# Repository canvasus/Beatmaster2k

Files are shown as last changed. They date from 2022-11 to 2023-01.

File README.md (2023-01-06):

# Beatmaster2k

A rudimentary step sequencer based on a Teensy 4.1 and a Novation Launchpad. 
It is mainly intended as a "jamming partner", not a full-fledged production tool.

Some basic features/specs:

- 7 Tracks. Can be set to output midi on serial, device or host ports
- 8 Patterns per track currently, but lots of room for expansion
- 64 Scenes, i.e combination of patterns

- Patterns are edited on the Launchpad. Works during playing
- Patterns can be set to any length between 1 and 128 steps
- Patterns have configurable speed

- Patterns and other settings stored on SD card

Component list:
- Teensy 4.1
- SD card
- ILI9341 display (touch is not used atm)
- 2 encoders
- 8 buttons via an MPC23017 expander
- Powered usb hub
- Novation Launchpad Mini Mk3

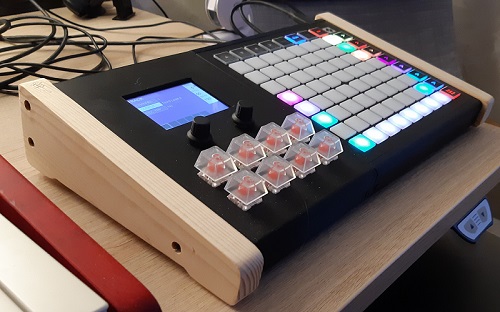
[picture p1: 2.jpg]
prototype1


(prototype assembly)

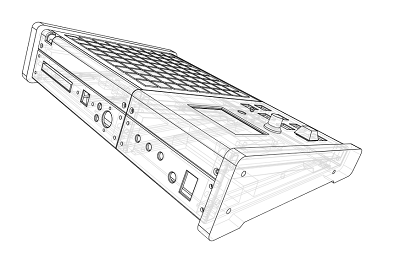
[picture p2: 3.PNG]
cad


(parts for 3D print and milling in Onshape)

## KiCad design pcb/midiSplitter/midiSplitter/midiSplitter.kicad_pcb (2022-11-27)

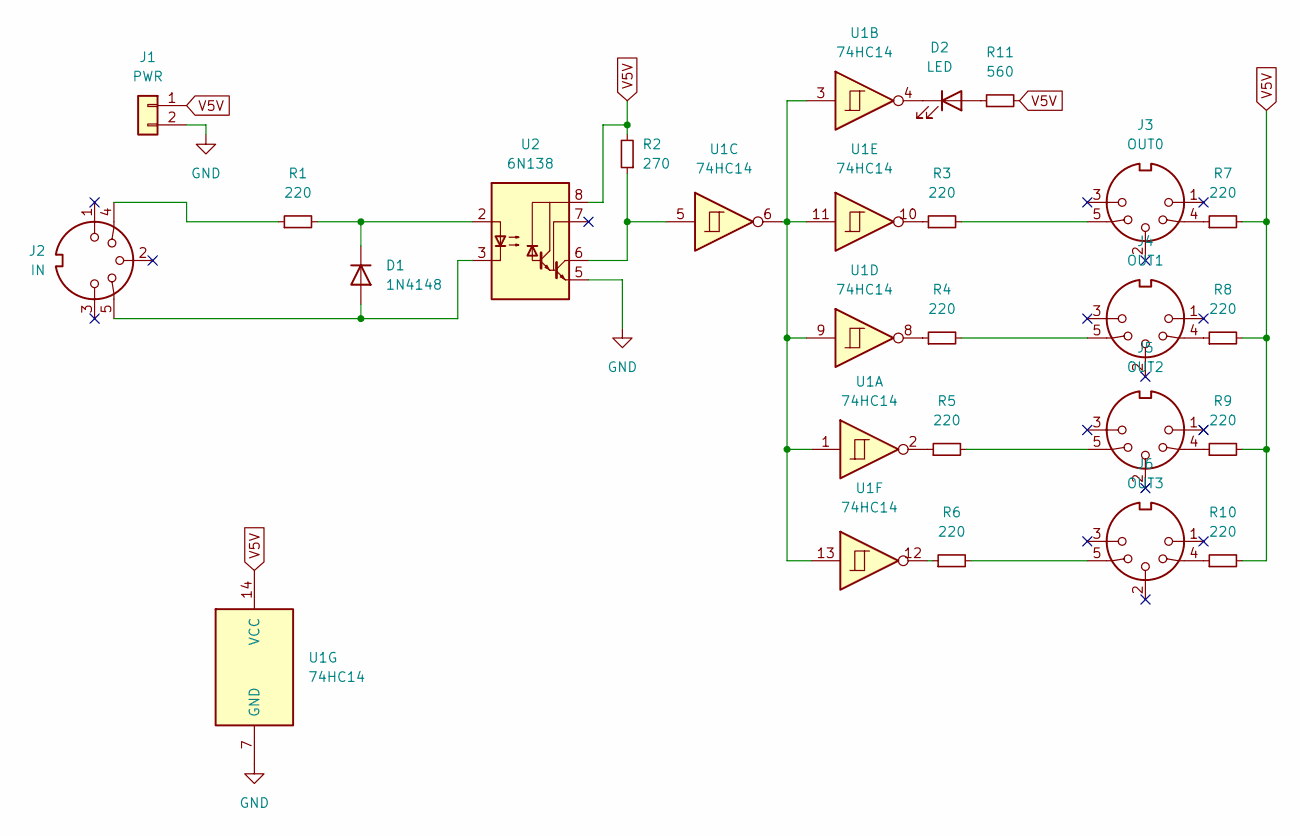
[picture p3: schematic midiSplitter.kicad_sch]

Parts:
D1: 1N4148; D_DO-35_SOD27_P7.62mm_Horizontal
D2: LED; LED_D3.0mm
J1: PWR; PinHeader_1x02_P2.54mm_Vertical
J2: IN; MIDI_DIN5
J3: OUT0; MIDI_DIN5
J4: OUT1; MIDI_DIN5
J5: OUT2; MIDI_DIN5
J6: OUT3; MIDI_DIN5
R1, R3, R4, R5, R6, R7, R8, R9, R10: 220; R_Axial_DIN0204_L3.6mm_D1.6mm_P5.08mm_Horizontal
R2: 270; R_Axial_DIN0204_L3.6mm_D1.6mm_P5.08mm_Horizontal
R11: 560; R_Axial_DIN0204_L3.6mm_D1.6mm_P5.08mm_Horizontal
U1: 74HC14; DIP-14_W7.62mm
U2: 6N138; DIP-8_W7.62mm

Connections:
GND: J1.2, U1.7 (GND), U2.5 (GND)
unnamed: D1.1 (K), R1.2, U2.2 (C1)
unnamed: D1.2 (A), J2.5, U2.3 (C2)
unnamed: D2.2 (A), R11.1
unnamed: J2.4, R1.1
unnamed: R2.1, U1.5, U2.6 (VO2)
unnamed: R3.1, U1.10
unnamed: J3.5, R3.2
unnamed: R4.1, U1.8
unnamed: J4.5, R4.2
unnamed: R5.1, U1.2
unnamed: J5.5, R5.2
unnamed: R6.1, U1.12
unnamed: J6.5, R6.2
unnamed: J3.4, R7.1
unnamed: J4.4, R8.1
unnamed: J5.4, R9.1
unnamed: J6.4, R10.1
unnamed: D2.1 (K), U1.4
unnamed: U1.1, U1.3, U1.6, U1.9, U1.11, U1.13
V5V: J1.1, R2.2, R7.2, R8.2, R9.2, R10.2, R11.2, U1.14 (VCC), U2.8 (VCC)

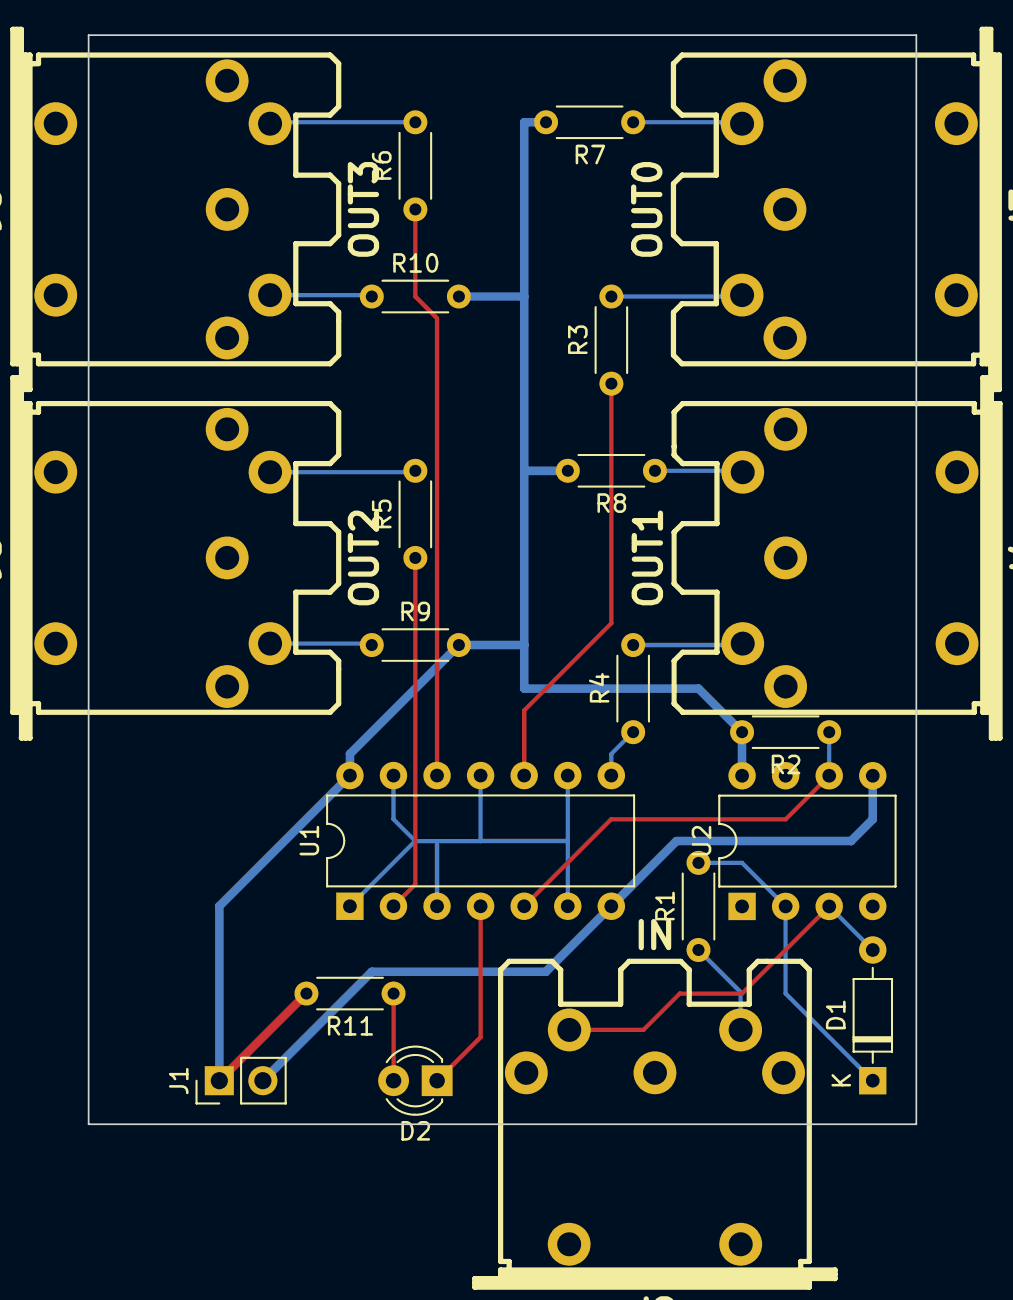
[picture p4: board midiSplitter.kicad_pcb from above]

Board: 2 copper layers, 48.3 x 63.5 mm, 21 parts (0 on the bottom side), 21 nets.

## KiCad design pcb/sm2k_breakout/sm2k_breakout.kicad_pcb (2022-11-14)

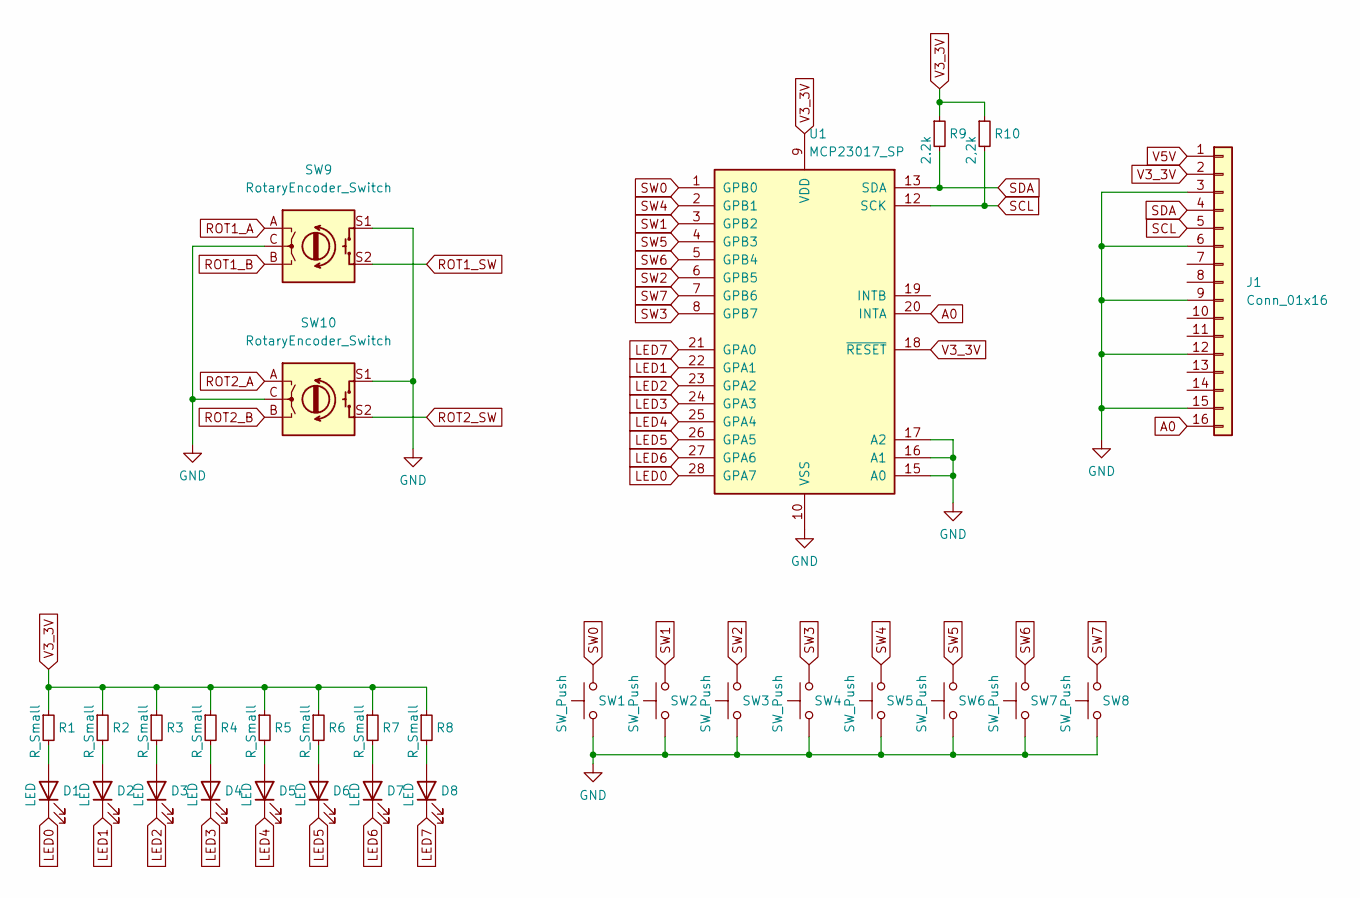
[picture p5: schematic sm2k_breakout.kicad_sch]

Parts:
D1, D2, D3, D4, D5, D6, D7, D8: LED; LED_D3.0mm
J1: Conn_01x16; IDC-Header_2x08_P2.54mm_Vertical
R1, R2, R3, R4, R5, R6, R7, R8: R_Small; R_0603_1608Metric_Pad0.98x0.95mm_HandSolder
R9: 2.2k; R_0603_1608Metric_Pad0.98x0.95mm_HandSolder
R10: 2,2k; R_0603_1608Metric_Pad0.98x0.95mm_HandSolder
SW1, SW2, SW3, SW4, SW5, SW6, SW7, SW8: SW_Push; SW_Cherry_MX_1.00u_PCB
SW9, SW10: RotaryEncoder_Switch; RotaryEncoder_Alps_EC11E-Switch_Vertical_H20mm_CircularMoun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
U1: MCP23017_SP; DIP-28_W7.62mm

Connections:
A0: J1.16, U1.20 (INTA)
GND: J1.3, J1.6, J1.9, J1.12, J1.15, SW1.1, SW2.1, SW3.1, SW4.1, SW5.1, SW6.1, SW7.1, SW8.1, SW9.C, SW9.S1, SW10.C, SW10.S1, U1.10 (VSS), U1.15 (A0), U1.16 (A1), U1.17 (A2)
LED0: D1.1 (K), U1.28 (GPA7)
LED1: D2.1 (K), U1.22 (GPA1)
LED2: D3.1 (K), U1.23 (GPA2)
LED3: D4.1 (K), U1.24 (GPA3)
LED4: D5.1 (K), U1.25 (GPA4)
LED5: D6.1 (K), U1.26 (GPA5)
LED6: D7.1 (K), U1.27 (GPA6)
LED7: D8.1 (K), U1.21 (GPA0)
unnamed: D1.2 (A), R1.2
unnamed: D2.2 (A), R2.2
unnamed: D3.2 (A), R3.2
unnamed: D4.2 (A), R4.2
unnamed: D5.2 (A), R5.2
unnamed: D6.2 (A), R6.2
unnamed: D7.2 (A), R7.2
unnamed: D8.2 (A), R8.2
ROT1_A: SW9.A
ROT1_B: SW9.B
ROT1_SW: SW9.S2
ROT2_A: SW10.A
ROT2_B: SW10.B
ROT2_SW: SW10.S2
SCL: J1.5, R10.2, U1.12 (SCK)
SDA: J1.4, R9.2, U1.13 (SDA)
SW0: SW1.2, U1.1 (GPB0)
SW1: SW2.2, U1.3 (GPB2)
SW2: SW3.2, U1.6 (GPB5)
SW3: SW4.2, U1.8 (GPB7)
SW4: SW5.2, U1.2 (GPB1)
SW5: SW6.2, U1.4 (GPB3)
SW6: SW7.2, U1.5 (GPB4)
SW7: SW8.2, U1.7 (GPB6)
V3_3V: J1.2, R1.1, R2.1, R3.1, R4.1, R5.1, R6.1, R7.1, R8.1, R9.1, R10.1, U1.9 (VDD), U1.18 (~RESET)
V5V: J1.1

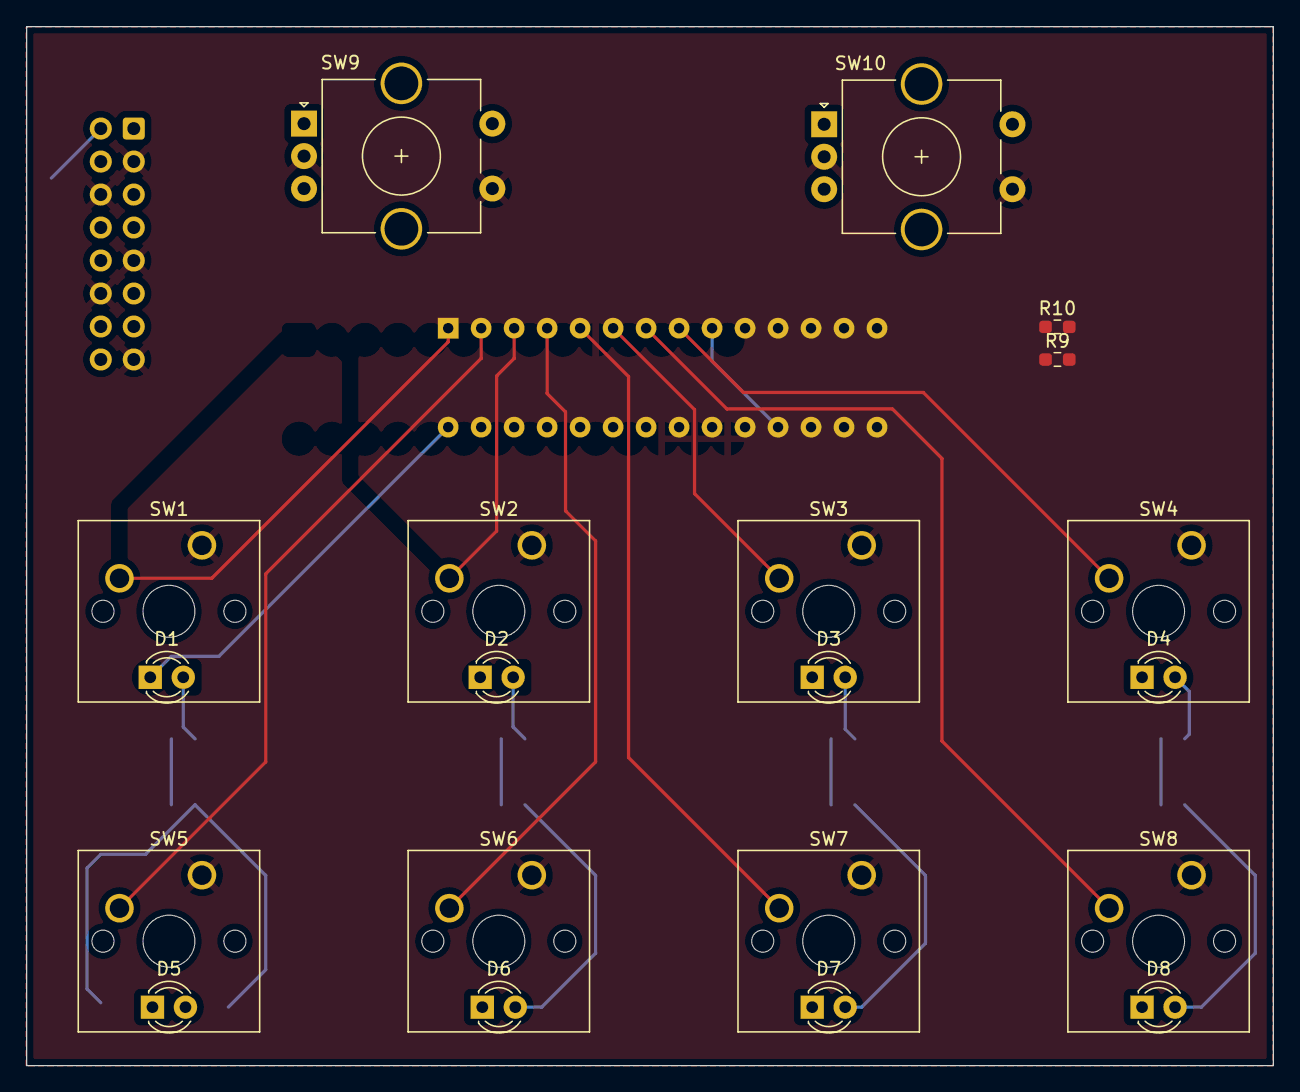
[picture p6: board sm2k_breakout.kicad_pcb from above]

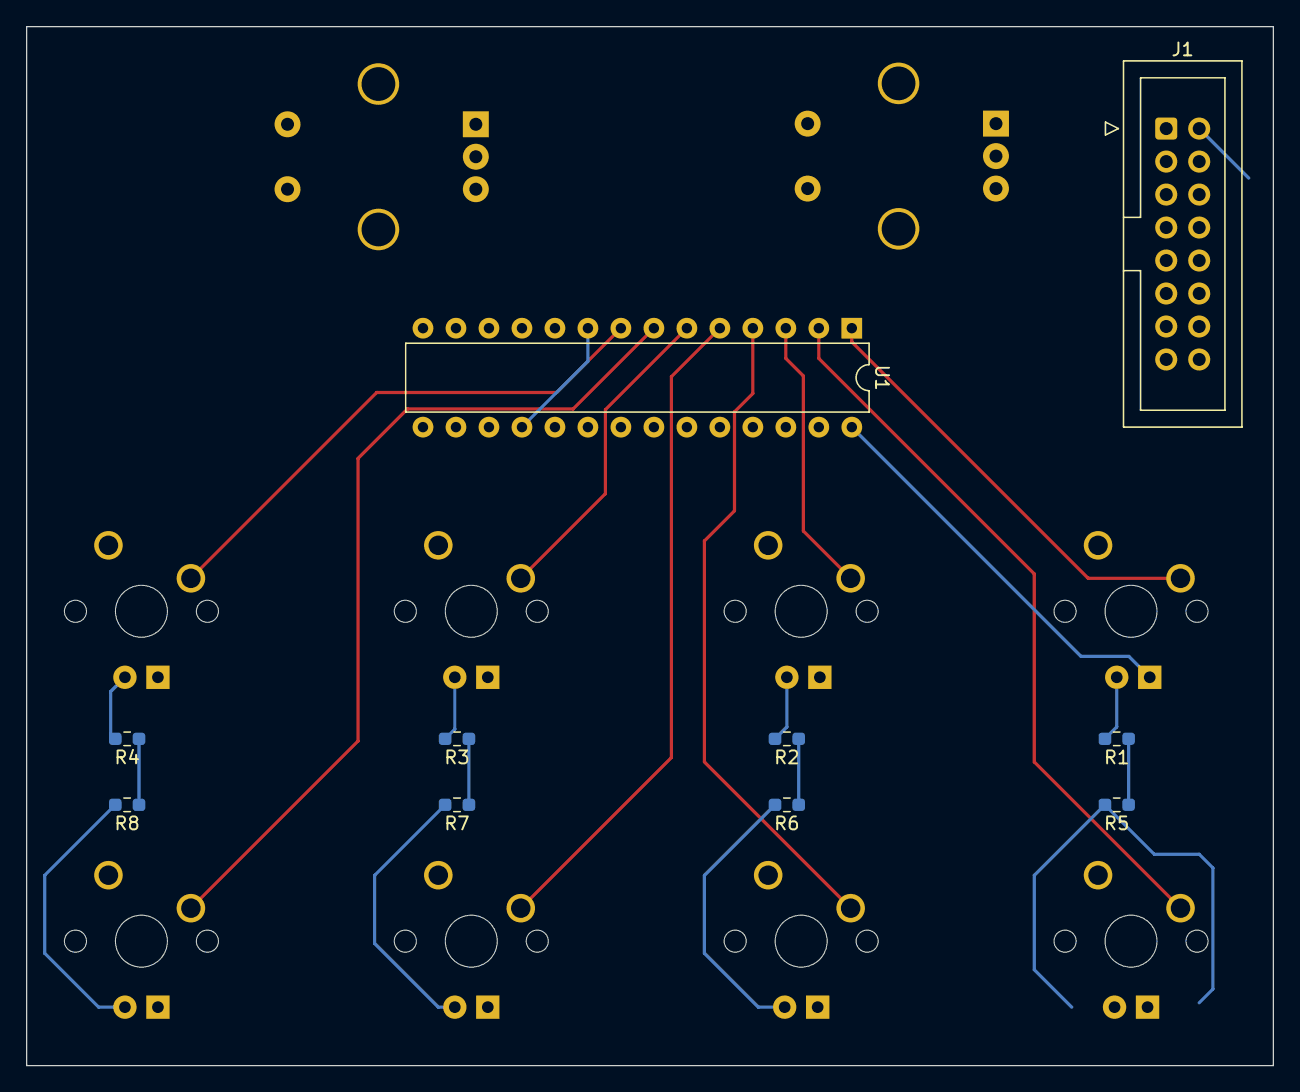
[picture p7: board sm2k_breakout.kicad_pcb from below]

Board: 2 copper layers, 96.0 x 80.0 mm, 30 parts (10 on the bottom side), 29 nets.

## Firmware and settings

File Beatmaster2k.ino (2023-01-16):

#include "midiFunctions.h"
#include "audioFunctions.h"
#include "sequencer.h"
#include "ui.h"
#include "sdMgr.h"

void setup()
{
  Serial.println(F("START"));
  if (CrashReport) Serial.print(CrashReport);
  setupUI();
  setupMidi();
  setupAudio();
  initSDcard();
  initSequencer();
}

void loop()
{
  updateMidi();
  updateUI();
  updateSequencer();
}

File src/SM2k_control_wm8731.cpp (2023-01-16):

/* Audio Library for Teensy 3.X
 * Copyright (c) 2014, Paul Stoffregen, paul@pjrc.com
 *
 * Development of this audio library was funded by PJRC.COM, LLC by sales of
 * Teensy and Audio Adaptor boards.  Please support PJRC's efforts to develop
 * open source software by purchasing Teensy or other PJRC products.
 *
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
 * THE SOFTWARE IS PROVIDED "AS IS", WITHOUT WARRANTY OF ANY KIND, EXPRESS OR
 * IMPLIED, INCLUDING BUT NOT LIMITED TO THE WARRANTIES OF MERCHANTABILITY,
 * FITNESS FOR A PARTICULAR PURPOSE AND NONINFRINGEMENT. IN NO EVENT SHALL THE
 * AUTHORS OR COPYRIGHT HOLDERS BE LIABLE FOR ANY CLAIM, DAMAGES OR OTHER
 * LIABILITY, WHETHER IN AN ACTION OF CONTRACT, TORT OR OTHERWISE, ARISING FROM,
 * OUT OF OR IN CONNECTION WITH THE SOFTWARE OR THE USE OR OTHER DEALINGS IN
 * THE SOFTWARE.
 */

#include <Arduino.h>
#include "SM2k_control_wm8731.h"
#include "Wire.h"

#define WM8731_I2C_ADDR 0x1A
//#define WM8731_I2C_ADDR 0x1B

#define WM8731_REG_LLINEIN	0
#define WM8731_REG_RLINEIN	1
#define WM8731_REG_LHEADOUT	2
#define WM8731_REG_RHEADOUT	3
#define WM8731_REG_ANALOG	4
#define WM8731_REG_DIGITAL	5
#define WM8731_REG_POWERDOWN	6
#define WM8731_REG_INTERFACE	7
#define WM8731_REG_SAMPLING	8
#define WM8731_REG_ACTIVE	9
#define WM8731_REG_RESET	15

void SM2k_AudioControlWM8731::setAddress(uint8_t address)
{
  i2c_address = address;
}

bool SM2k_AudioControlWM8731::enable(void)
{
	Wire.begin();
	delay(100);
#if 1
	if (!write(WM8731_REG_RESET, 0)) {
		return false; // no WM8731 chip responding
	}
#endif
	write(WM8731_REG_INTERFACE, 0x02); // I2S, 16 bit, MCLK slave
	write(WM8731_REG_SAMPLING, 0x20);  // 256*Fs, 44.1 kHz, MCLK/1

	// In order to prevent pops, the DAC should first be soft-muted (DACMU),
	// the output should then be de-selected from the line and headphone output
	// (DACSEL), then the DAC powered down (DACPD).

	write(WM8731_REG_DIGITAL, 0x08);   // DAC soft mute
	write(WM8731_REG_ANALOG, 0x00);    // disable all

	write(WM8731_REG_POWERDOWN, 0x00); // codec powerdown

	write(WM8731_REG_LHEADOUT, 0x80);      // volume off
	write(WM8731_REG_RHEADOUT, 0x80);

	delay(100); // how long to power up?

	write(WM8731_REG_ACTIVE, 1);
	delay(5);
	write(WM8731_REG_DIGITAL, 0x00);   // DAC unmuted
	write(WM8731_REG_ANALOG, 0x10);    // DAC selected

	return true;
}

// WM8731 has flaky I2C communication, especially when MCLK has ringing,
// overshoot or other high-speed signal quality issues.  Chips like
// Teensy 3.6 with very high bandwidth I/O pins should be used with
// caution.  A resistor or low-pass circuit may be needed.
//   https://forum.pjrc.com/threads/55334?p=201494&viewfull=1#post201494

bool SM2k_AudioControlWM8731::write(unsigned int reg, unsigned int val)
{
	int attempt=0;
	//Serial.printf("WM8731 %d, reg %d, val %d: ", i2c_address, reg, val);
	while (1) {
		attempt++;
		//Wire.beginTransmission(WM8731_I2C_ADDR);
		Wire.beginTransmission(i2c_address);
		Wire.write((reg << 1) | ((val >> 8) & 1));
		Wire.write(val & 0xFF);
		int status = Wire.endTransmission();
		if (status == 0) {
			//Serial.printf("write ok, %d tries\n", attempt);
			return true;
		}
		if (attempt >= 12) {
			Serial.printf("write failed %d tries\n", attempt);
			return false;
		}
		delayMicroseconds(80);
	}
}

bool SM2k_AudioControlWM8731::volumeInteger(unsigned int n)
{
	// n = 127 for max volume (+6 dB)
	// n = 48 for min volume (-73 dB)
	// n = 0 to 47 for mute
	if (n > 127) n = 127;
	 //Serial.print("volumeInteger, n = ");
	 //Serial.println(n);
	write(WM8731_REG_LHEADOUT, n | 0x180);
	write(WM8731_REG_RHEADOUT, n | 0x80);
	return true;
}

bool SM2k_AudioControlWM8731::inputLevel(float n)
{
	// range is 0x00 (min) - 0x1F (max)

	int _level = int(n * 31.f); 

	_level = _level > 0x1F ? 0x1F : _level;
	write(WM8731_REG_LLINEIN, _level);
	write(WM8731_REG_RLINEIN, _level);
	return true;
}

bool SM2k_AudioControlWM8731::inputSelect(int n)
{
	if (n == AUDIO_INPUT_LINEIN) {
		write(WM8731_REG_ANALOG, 0x12);
	} else if (n == AUDIO_INPUT_MIC) {
		write(WM8731_REG_ANALOG, 0x15);
	} else {
		return false;
	}
	return true;
}

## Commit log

2022-09-29 Added sidechain
    [doxygen.cfg]
2022-10-09 SPI display
    [sm2kPinUsage.xlsx, sm2k_breakout.kicad_pcb, sm2k_breakout.kicad_sch]
2022-11-12 button matrix
    [sm2k_breakout.kicad_pcb, sm2k_breakout.kicad_sch]
2022-11-14 Ui fixes
    [parameters.xlsx, sm2k_breakout.kicad_pcb, sm2k_breakout.kicad_sch]
2022-11-27 More UI
    [midiSplitter.kicad_pcb, midiSplitter.kicad_sch]
2022-12-11 removed audio, cued mute
    [dataStorage.xlsx]
2022-12-26 Scenes and chain
2022-12-29 Tools and chaining
2023-01-02 fixed track change crash
    [midiFunctions.cpp, sdMgr.cpp]
2023-01-04 minor cleanup
    [dataStorage.xlsx, parameters.xlsx, sm2kPinUsage.xlsx]
2023-01-21 Added samples
